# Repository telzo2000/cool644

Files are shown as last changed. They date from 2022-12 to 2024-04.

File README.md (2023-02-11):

# cool644
<br><br>

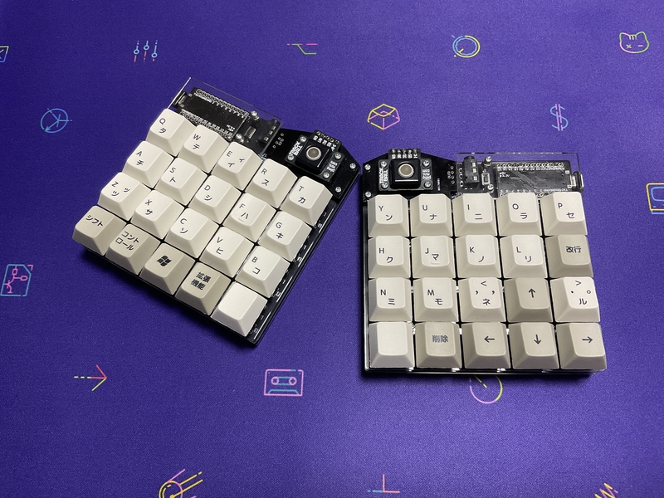
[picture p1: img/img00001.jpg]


# What is cool644?

<br>
cool644 is 40% keyboards.
<br>
cool644 is an evolution of cool640.
<br>
The cool644 can use rotary encoders and trackballs.
<br>
cool640 is written here.https://github.com/telzo2000/cool640

# History

ver.1.21 Compatible with AZ1UBALL
<br>
ver.1.1 First release
<br>
<br>
# Build guide 

https://github.com/telzo2000/cool644/blob/main/buildguide_for_cool644.md

<br>

# Sales site

https://booth.pm/ja/items/3729914

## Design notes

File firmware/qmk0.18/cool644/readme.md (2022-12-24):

# cool644

cool644

*A short description of the keyboard/project*

* Keyboard Maintainer: [m.ki](https://github.com/telzo2000)
* Hardware Supported: *The PCBs, controllers supported*
* Hardware Availability: *Links to where you can find this hardware*

Make example for this keyboard (after setting up your build environment):

    make cool644:default

Flashing example for this keyboard:

    make cool644:default:flash

See the [build environment setup](https://docs.qmk.fm/#/getting_started_build_tools) and the [make instructions](https://docs.qmk.fm/#/getting_started_make_guide) for more information. Brand new to QMK? Start with our [Complete Newbs Guide](https://docs.qmk.fm/#/newbs).

## Bootloader

Enter the bootloader in 3 ways:

* **Bootmagic reset**: Hold down the key at (0,0) in the matrix (usually the top left key or Escape) and plug in the keyboard
* **Physical reset button**: Briefly press the button on the back of the PCB - some may have pads you must short instead
* **Keycode in layout**: Press the key mapped to `QK_BOOT` if it is available

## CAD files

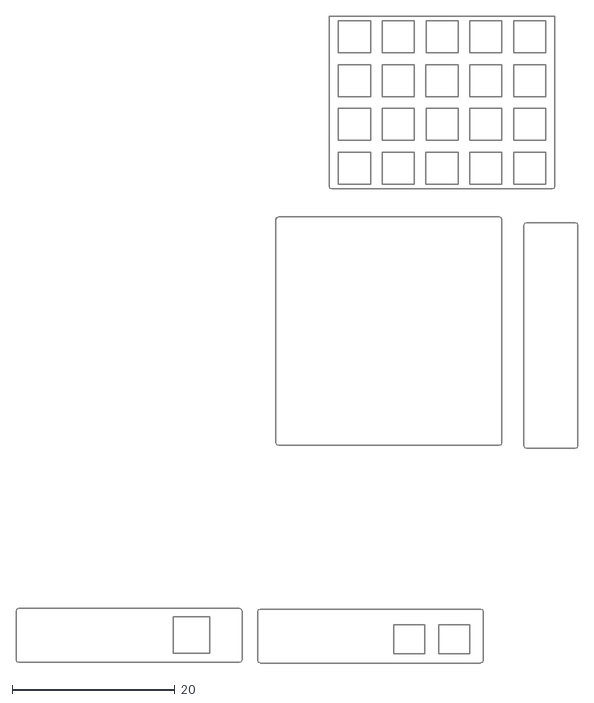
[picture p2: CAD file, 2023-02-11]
case_design/plate_elecrow200x250.dxf
69.0 x 79.4

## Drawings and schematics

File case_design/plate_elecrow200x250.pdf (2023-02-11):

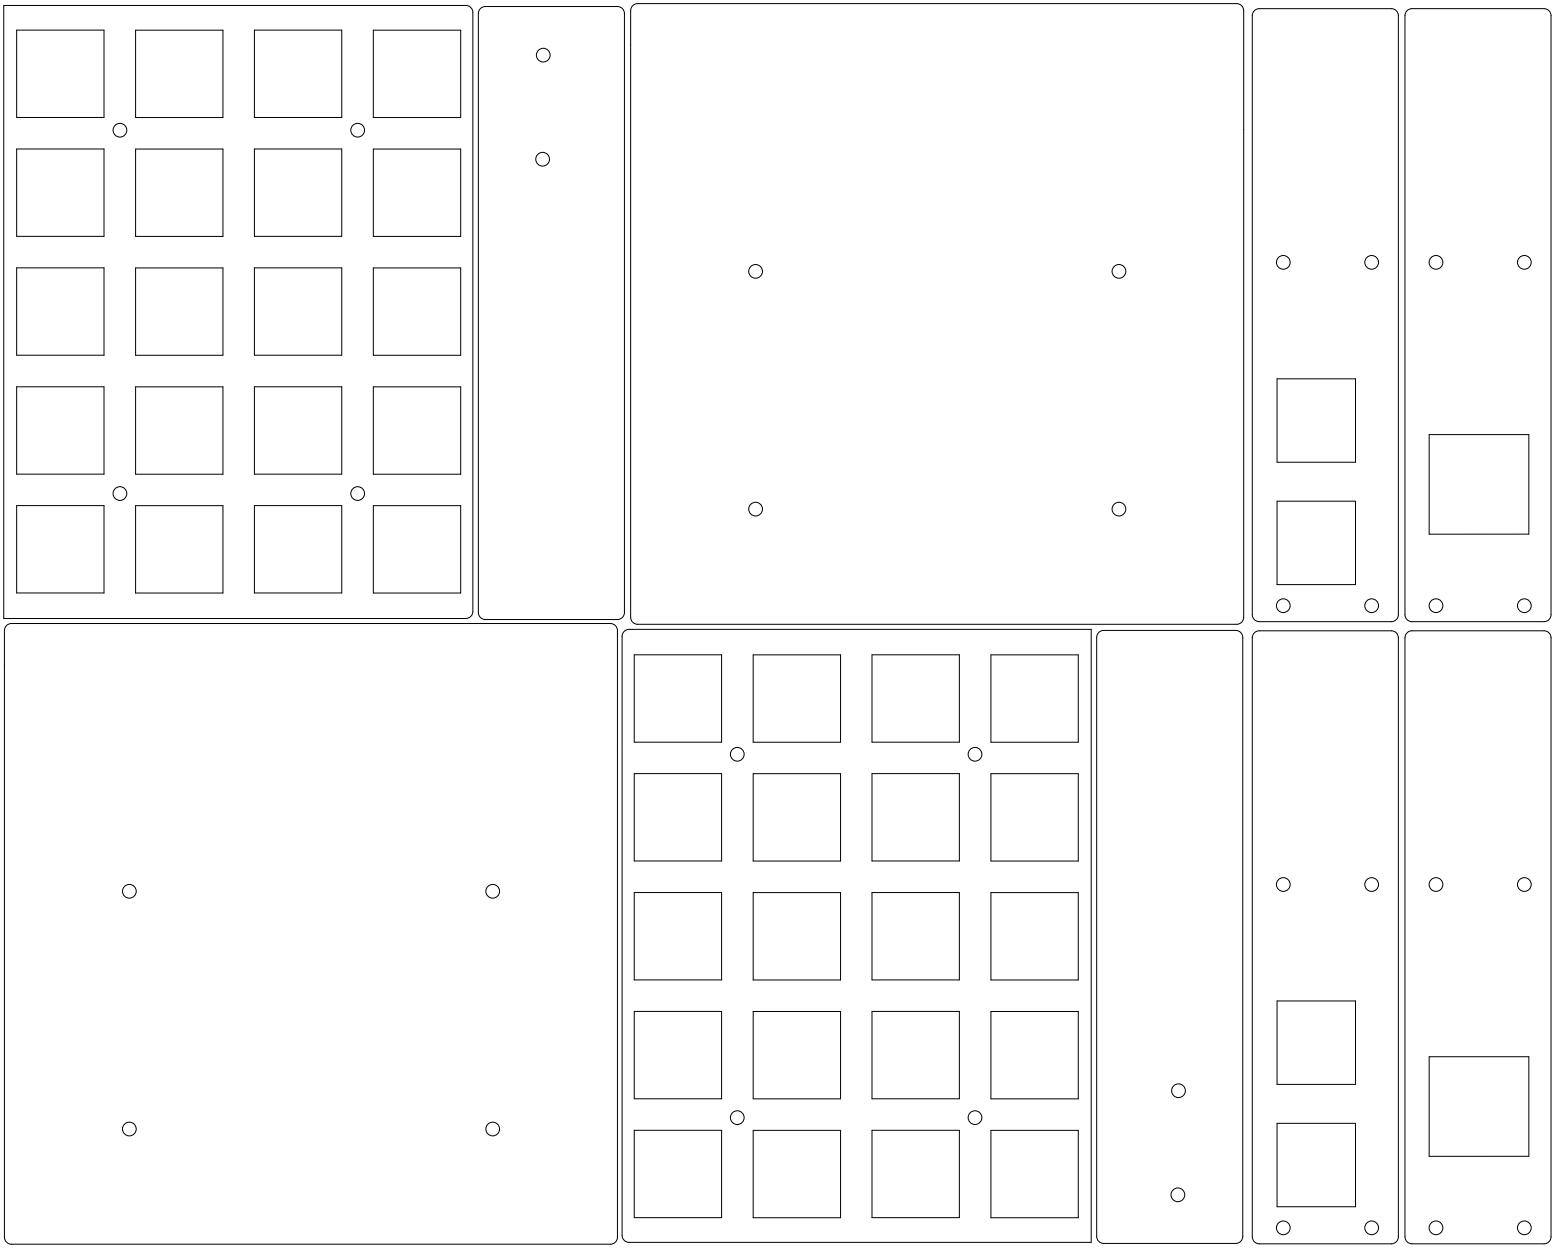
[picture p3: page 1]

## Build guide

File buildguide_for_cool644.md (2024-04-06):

# Build guide

## Parts list

| No. | Patrs | Quantity | remarks | Suppliers | Cost |
|--|--|--|--|--|--|
|番号|名前|数|備考|調達先|参考価格（送料込）|<br>
|1|PCB|2|40%splite keyboard|[elecrow](https://www.elecrow.com)<br>[JLCPCB](https://jlcpcb.com)<br>[ALLPCB](https://www.allpcb.com)|５枚で10〜20ドル|<br>
|2-1|Switch Plate<br>スイッチプレート|2|アクリル<br>[Plate data](https://github.com/telzo2000/cool536/tree/main/case_design)|[工房Emerge+](https://www.emergeplus.jp/laser-cutting-service/contact/)<br>[遊舎工房](https://yushakobo.jp)<br>[elecrow](https://www.elecrow.com)|種類による。|
|2-2|Cover Plate<br>カバープレート|2|↑|↑|↑|
|2-3|Bottom Plate<br>ボトムプレート|2|↑|↑|↑|
|3|M2screw<br>M2ネジ|8〜16|4mm<br>CoverPlateで使用<br>3mmでも代用可|DIYショップなど|10本で100円程度|
|4|M2screw<br>M2ネジ|8|3mm<br>BottomPlateで使用|↑|↑|
|5A|M2screw<br>M2ネジ|8|8mm<br>MXスイッチ使用時SwitchPlateで使用|↑|↑|
|5B|M2screw<br>M2ネジ|8|6mm<br>chocスッチ使用時SwitchPlateで使用|↑|↑|
|6A|M2spacer<br>M2スペーサー|16|3mmメス-メス<br>MXスイッチ使用時|[ヒロスギネット](https://www.hirosugi-net.co.jp/shop/c/c10/)<br>[遊舎工房](https://yushakobo.jp)|20本で800円程度|
|6B|M2spacer<br>M2スペーサー|8|3mmメス-メス<br>chocスイッチ使用時|[ヒロスギネット](https://www.hirosugi-net.co.jp/shop/c/c10/)<br>[遊舎工房](https://yushakobo.jp)|20本で800円程度|
|7|M2spacer<br>M2スペーサー|4〜8|6mmまたは8mmメス-メス<br>CoverPlateで使用|[ヒロスギネット](https://www.hirosugi-net.co.jp/shop/c/c10/)<br>[遊舎工房](https://yushakobo.jp)|20本で800円程度|
|8|pro micro|2|ピンヘッダも別途購入|[遊舎工房](https://yushakobo.jp)<br>[Talp Keyboard](https://talpkeyboard.net)<br>[Daily Craft Keyboard](https://shop.dailycraft.jp)等|価格変動中|
|9A|Swith socket<br>スイッチソケット|40|cherry MX互換|[遊舎工房](https://yushakobo.jp)<br>[Talp Keyboard](https://talpkeyboard.net)<br>[Daily Craft Keyboard](https://shop.dailycraft.jp)等|10個で165円程度|
|9B|Swith socket<br>スイッチソケット|40|choc互換|[遊舎工房](https://yushakobo.jp)<br>[Talp Keyboard](https://talpkeyboard.net)<br>[Daily Craft Keyboard](https://shop.dailycraft.jp)等|10個で165円程度|
|10|Diode<br>ダイオード|40〜44|リードタイプでもSMDでも可|[遊舎工房](https://yushakobo.jp)<br>[Talp Keyboard](https://talpkeyboard.net)<br>[Daily Craft Keyboard](https://shop.dailycraft.jp)等|100個で220円程度から|
|11|タクトスイッチ|2|２本足のもの|[遊舎工房](https://yushakobo.jp)<br>[Talp Keyboard](https://talpkeyboard.net)<br>[Daily Craft Keyboard](https://shop.dailycraft.jp)等|１個11円程度|
|12|TRRSジャック|2|MJ-4PP-9|[遊舎工房](https://yushakobo.jp)<br>[Talp Keyboard](https://talpkeyboard.net)<br>[Daily Craft Keyboard](https://shop.dailycraft.jp)等|１個55円|

In addition, you will need a TRRS cable, USB cable, keycaps, etc.
<br>
この他に、TRRSケーブル、USBケーブル、キーキャップ等が必要です。
<br>

## Firmware

###  QMK_FIRMWARE
[Here](https://github.com/telzo2000/cool644/tree/main/firmware)

<br>
[remap](https://remap-keys.app/)

<br>

## Build 1(PCB only)

### 1 Parts check

The cool644 is a PCB that uses both the front and back sides for left and right PCBs.
<br>
The part where the corner is cut diagonally will be the outside of the left and right.
<br>
<br>
cool644は左右のPCBに対して、表裏両面を使用するPCBです。
<br>
角が斜めにカットされている箇所が、左右の外側になります。
<br>

### 2 Diode soldering

Solder the diodes to the back of each of the left and right.
<br>
左右それぞれの裏面にダイオードのハンダ付けをします。
<br>

There are lead type and SMD diodes.
<br>
ダイオードはリードタイプか、SMDがあります。
<br>
Here, we will explain the lead type soldering.
<br>
ここでは、リードタイプのハンダ付けの説明をします。
<br>
However, those who adopt the choc switch should use SMD diodes.
<br>
ただし、chocスイッチを採用する人は、SMDのダイオードを使用してください。
<br>

Use a lead bender to bend the legs of the diode.
<br>
リードベンダーを使い、ダイオードの足を曲げます。
<br>

Insert the diode into the board.
<br>
ダイオードを基板に挿しこみます。
<br>

Please pay attention to the orientation of the diode.
<br>
ダイオードの向きに注意してください。
<br>

Secure the diode with masking tape, then face up.
<br>
マスキングテープでダイオードを固定してから、表面を上にします。
<br>
Solder the protruding legs.
<br>
はみ出ている足部分に、ハンダ付けをします。
<br>
After soldering, use nippers to cut off the protruding legs.
<br>
はんだ付けが終わったら、はみ出ている足をニッパーで切り取ってください。
<br>

[８倍速　Diodeハンダ付け動画](https://youtu.be/Yaodh2-XxV4)

<br>
<br>

### 3 Soldering switch sockets

Solder the switch sockets on the back side.
<br>
裏面にスイッチソケットのハンダ付けをします。
<br>
cool644 is compatible with both choc and cherry MX switches.
<br>
cool644はchocスイッチとcherryMXスイッチの両方に対応しています。
<br>
Both can be installed.
<br>
両方を取り付けることが可能です。
<br>
Here, solder the cherryMX switch.
<br>
ここでは、cherryMXスイッチのハンダ付けを行います。
<br>
Place the switch socket so that the letters MX are hidden.
<br>
MXという文字が隠れるように、スイッチソケットを乗せてください。
<br>
That is the correct switch socket orientation.
<br>
それが正しいスイッチソケットの向きになります。
<br>
When using a choc switch, place the switch socket so that the letters choc are hidden.
<br>
chocスイッチの時は、chocという文字が隠れるように、スイッチソケットを乗せてください。
<br>

Apply solder to both pads.
<br>
両方のパッドにハンダを盛ります。
<br>
Place the switch socket and fix it with a warm soldering iron while melting the solder.
<br>
スイッチソケットを乗せて、温めたハンダゴテで、ハンダを溶かしながら、固定します。
<br>
You can make it easier by working while holding it with tweezers.
<br>
ピンセットで押さえながら、作業をすると楽にできます。
<br>

[８倍速　Switch socketハンダ付け動画](https://youtu.be/E__mHvmIXQo)

<br><br>

### 4 Soldering reset switch & TRRS jack 

Insert the reset switch on the surface.
<br>
表面にリセットスイッチを挿しこみます。
<br>
Solder the legs of the reset switch from the back.
<br>
裏面からリセットスイッチの足をハンダ付けします。
<br>
Solder the TRRS jack in the same way near the reset switch.
<br>
TRRSジャックは、リセットスイッチの近くに同じようにハンダ付けします。
<br>
Insert the left and right TRRS jacks from the front side and solder from the back side.
<br>
TRRSジャックは左右１箇所ずつ、表面から差し込み、裏面からはんだ付けをしてください。
<br>

[８倍速　Reset switch,TRRS jackハンダ付け動画](https://youtu.be/3gEbExaOAv4)

<br><br>

### 5　Pro micro 

cool644 requires pro micro on each side.
<br>
cool644は左右それぞれにpro microが必要となります。
<br>

Use the conthrough to fix the pro micro with the side with the parts facing down.
<br>
pro microの部品のある面を下向きに、コンスルーを使い、固定してください。
<br>

Pay attention to the orientation of the conthrough.
<br>
コンスルーの向きに注意してください。
<br>

<br>

### 6　Test

Please write the firmware and check the operation.
<br>
ファームウェアを書き込んで、動作確認をしてください。
<br>

Install a switch or measure continuity with tweezers, etc.
<br>
スイッチを取り付けるか、ピンセット等で導通をはかるかを行います。
<br>

<br>

### QMK_FIRMWARE
[Here](https://github.com/telzo2000/cool644/tree/main/firmware)

参考<br>

https://github.com/telzo2000/Hello_keyboard/blob/main/readme_about_firmware.md

<br>
[remap](https://remap-keys.app/)

<br>

remapの画面
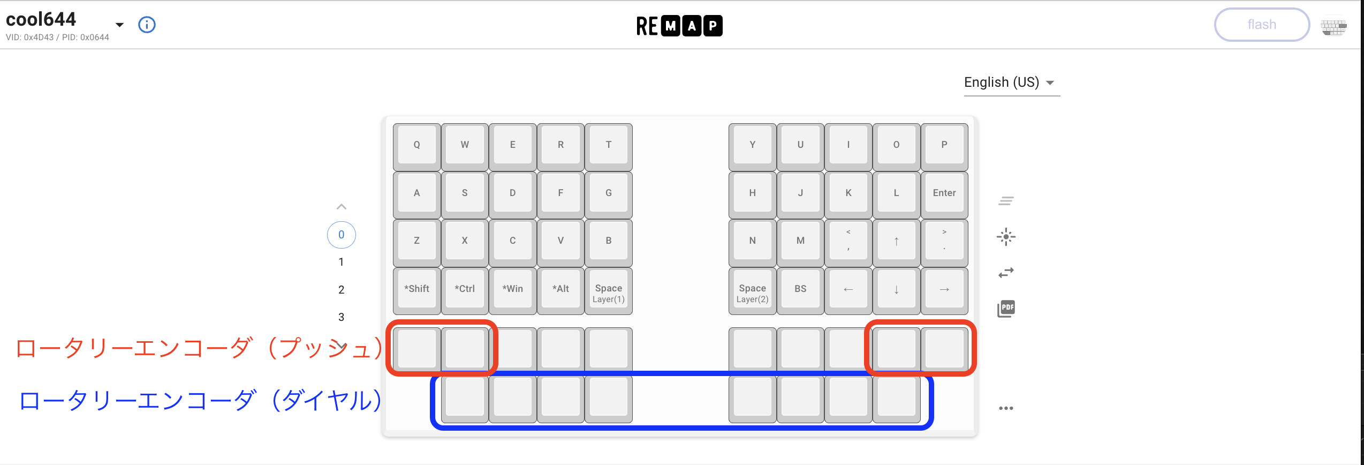
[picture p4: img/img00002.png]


<br>

### 7 Installation of key switch

Attach your favorite key switch.
<br>
好きなキースイッチを取り付けてください。
<br>

<br>
If you like, attach a rubber cushion to the back and you're done.
<br>
お好みで裏面にラバークッションを取り付けたら、完成です。
<br>
<br>
<br>

### Option 1 Installing a rotary encoder

cool644 can be equipped with 1 to 2 rotary encoders on the left and right, for a total of 4 rotary encoders.
<br>
cool644は、左右に１〜２個、合計４個のロータリーエンコーダーを取り付けることができます。
<br><br>

### Option 2 Mounting the OLED display

The left side of the cool644 can be fitted with an OLED display.
<br>
In that case, the rotary encoder cannot be attached to the left side of the cool644.
<br>
cool644の左側には、OLEDディスプレイを取り付けることができます。
<br>
その場合、cool644の左側には、ロータリーエンコーダーを取り付けることができません。
<br>
<br>

### OPtion 3 Installing PIM447 Trackball

You can install the PIM447 on either the left or right side.
<br>
In that case, you will need trackballpart.
<br><br>
左右どちらでも、PIM447を取り付けることができます。
<br>
その時は、trackballpartが必要となります。
<br>
<br>
In addition to PIM447 and trackballpart, you will need 10 M2 screws, 6 M2 spacers 3mm, and a pin header.
<br><br>
PIM447とtrackballpartの他に、M2ネジ10本、M2スペーサー3mm、ピンヘッダが必要となります。
<br><br>





<br><br><br>

## Build 2(Acrylic sandwich mount case)



After 1 ~ 6 of build1, please do the next step.
<br>
build1の1~6の後、次の工程をしてください。
<br>

### 1 Installation of cover plate

The same cover plate as cool640 can be used.
<br>
カバープレートはcool640と同じものが使えます。
<br>
And you can also use the cover plate dedicated to cool644.
<br>
そして、cool644専用のカバープレートも使えます。
<br><br>

Prepare a cover plate, M2 spacer 6or8mm（x４）, and M2 screw 4mm（x８）.
<br>
カバープレート、M2スペーサー6または8mm（４個）、M2ネジ3mm（８本）を用意します。
<br>
Screw the spacer to the cover plate in the same orientation.
<br>
カバープレートに同じ向きで、スペーサーをネジで固定します。
<br>
Then use the remaining screws to attach the cover plate to the PCB.
<br>
次に、残りのネジを使い、カバープレートをPCBに取り付けます。
<br>
There is an orientation of the cover plate, so it is good to check it once before starting work.
<br>
カバープレートの向きがあり、作業前に一度、重ねて確認すると良いです。
<br>
<br>
A special cover plate is required when installing a rotary encoder or an OLED display.
<br>
ロータリーエンコーダーまたはOLEDディスプレイを取り付けているとき、専用のカバープレートが必要となります。
<br><br>

### 2-1 Installation of switch plate（choc switch）

Prepare a switch plate, M2 spacer 3 mm（x４）, and M2 screw 6 mm（x４）.
<br>
スイッチプレート、M2スペーサー３mm（４本）、M2ネジ６mm（４本）を用意します。
<br>
Fix the screws in 4 places.
<br>
ネジを４箇所、固定します。
<br>
Insert the screws in the order of the switch plate and the PCB, and fix them with spacers on the back of the PCB.
<br>
ネジはスイッチプレート、PCBの順でさしこみ、PCBの裏面でスペーサーで固定します。
<br>

<br>

### 2-2 Installation of switch plate（cherry MX switch）

Prepare a switch plate, M2 spacer 3 mm（x８）, and M2 screw 8 mm（x４）.
<br>
スイッチプレート、M2スペーサー３mm（８本）、M2ネジ８mm（４本）を用意します。
<br>
Fix the screws in 4 places.
<br>
ネジを４箇所、固定します。
<br>
Insert the switch plate into the screw and fix it with a spacer.
<br>
ネジはスイッチプレートをさしこみ、スペーサーで固定します。
<br>
Next, insert the switch plate into the PCB and secure it with a spacer on the back of the PCB.
<br>
次に、スイッチプレートをPCBにさしこみ、PCBの裏面でスペーサーで固定します。
<br>

### 3 Installation of bottom plate 

Prepare the bottom plate and M2 ３mm screws（x４）.
<br>
ボトムプレート、M２ネジ３mm（４本）を用意します。
<br>
Place the bottom plate according to the spacer on the back of the PCB and fix it with screws.
<br>
PCB裏面にあるスペーサーに合わせて、ボトムプレートをのせて、ネジで固定します。
<br>
<br>
From here, proceed with step 7 of build1.
<br>
ここからは、build１の７の工程を進めてください。
<br>

Have a fun selfmade keyboard life!
<br>
楽しい自作キーボード生活を!



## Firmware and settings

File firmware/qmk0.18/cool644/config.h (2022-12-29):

// Copyright 2022 m.ki (@telzo2000)
// SPDX-License-Identifier: GPL-2.0-or-later

#pragma once

#include "config_common.h"

/* USB Device descriptor parameter */
#define VENDOR_ID    0x4D43
#define PRODUCT_ID   0x0644
#define DEVICE_VER   0x0001
#define MANUFACTURER telzo2000
#define PRODUCT      cool644

/* key matrix size */
#define MATRIX_ROWS 12
#define MATRIX_COLS 5

/*
 * Keyboard Matrix Assignments
 *
 * Change this to how you wired your keyboard
 * COLS: AVR pins used for columns, left to right
 * ROWS: AVR pins used for rows, top to bottom
 * DIODE_DIRECTION: COL2ROW = COL = Anode (+), ROW = Cathode (-, marked on diode)
 *                  ROW2COL = ROW = Anode (+), COL = Cathode (-, marked on diode)
 *
 */
#define MATRIX_ROW_PINS { B5, B4, B1, F7, F4, D0 }
#define MATRIX_COL_PINS { B2, B6, B3, F6, F5 }
#define MATRIX_ROW_PINS_RIGHT { B5, B4, B1, F7, F4, D0 }
#define MATRIX_COL_PINS_RIGHT { B2, B6, B3, F6, F5 }
#define UNUSED_PINS

/* COL2ROW, ROW2COL */
#define DIODE_DIRECTION ROW2COL
/*
 * Split Keyboard specific options, make sure you have 'SPLIT_KEYBOARD = yes' in your rules.mk, and define SOFT_SERIAL_PIN.
 */
#define SOFT_SERIAL_PIN D2  // or D1, D2, D3, E6

#define MASTER_LEFT
#define SOFT_SERIAL_PIN D2
//#define USE_I2C

#define ENCODERS_PAD_A {D4,D7 }
#define ENCODERS_PAD_B {C6,E6 }
#define ENCODERS_PAD_A_RIGHT {D7,D4 }
#define ENCODERS_PAD_B_RIGHT {E6,C6}


//#define LED_NUM_LOCK_PIN B0
//#define LED_CAPS_LOCK_PIN B1
//#define LED_SCROLL_LOCK_PIN B2
//#define LED_COMPOSE_PIN B3
//#define LED_KANA_PIN B4

//#define BACKLIGHT_PIN B7
//#define BACKLIGHT_LEVELS 3
//#define BACKLIGHT_BREATHING

#define RGB_DI_PIN D3
#ifdef RGB_DI_PIN
#    define RGBLED_NUM 16
#    define RGBLIGHT_HUE_STEP 8
#    define RGBLIGHT_SAT_STEP 8
#    define RGBLIGHT_VAL_STEP 8
#    define RGBLIGHT_LIMIT_VAL 255 /* The maximum brightness level */
#    define RGBLIGHT_SLEEP  /* If defined, the RGB lighting will be switched off when the host goes to sleep */
/*== all animations enable ==*/
#    define RGBLIGHT_ANIMATIONS
/*== or choose animations ==*/
#    define RGBLIGHT_EFFECT_BREATHING
#    define RGBLIGHT_EFFECT_RAINBOW_MOOD
#    define RGBLIGHT_EFFECT_RAINBOW_SWIRL
#    define RGBLIGHT_EFFECT_SNAKE
#    define RGBLIGHT_EFFECT_KNIGHT
#    define RGBLIGHT_EFFECT_CHRISTMAS
#    define RGBLIGHT_EFFECT_STATIC_GRADIENT
#    define RGBLIGHT_EFFECT_RGB_TEST
#    define RGBLIGHT_EFFECT_ALTERNATING
/*== customize breathing effect ==*/
/*==== (DEFAULT) use fixed table instead of exp() and sin() ====*/
#    define RGBLIGHT_BREATHE_TABLE_SIZE 256      // 256(default) or 128 or 64
/*==== use exp() and sin() ====*/
#    define RGBLIGHT_EFFECT_BREATHE_CENTER 1.85  // 1 to 2.7
#    define RGBLIGHT_EFFECT_BREATHE_MAX    255   // 0 to 255
#endif

/* Debounce reduces chatter (unintended double-presses) - set 0 if debouncing is not needed */
#define DEBOUNCE 5

/* define if matrix has ghost (lacks anti-ghosting diodes) */
//#define MATRIX_HAS_GHOST

/* Mechanical locking support. Use KC_LCAP, KC_LNUM or KC_LSCR instead in keymap */
#define LOCKING_SUPPORT_ENABLE
/* Locking resynchronize hack */
#define LOCKING_RESYNC_ENABLE

/* If defined, GRAVE_ESC will always act as ESC when CTRL is held.
 * This is useful for the Windows task manager shortcut (ctrl+shift+esc).
 */
//#define GRAVE_ESC_CTRL_OVERRIDE

/*
 * Force NKRO
 *
 * Force NKRO (nKey Rollover) to be enabled by default, regardless of the saved
 * state in the bootmagic EEPROM settings. (Note that NKRO must be enabled in the
 * makefile for this to work.)
 *
 * If forced on, NKRO can be disabled via magic key (default = LShift+RShift+N)
 * until the next keyboard reset.
 *
 * NKRO may prevent your keystrokes from being detected in the BIOS, but it is
 * fully operational during normal computer usage.
 *
 * For a less heavy-handed approach, enable NKRO via magic key (LShift+RShift+N)
 * or via bootmagic (hold SPACE+N while plugging in the keyboard). Once set by
 * bootmagic, NKRO mode will always be enabled until it is toggled again during a
 * power-up.
 *
 */
//#define FORCE_NKRO

/*
 * Feature disable options
 *  These options are also useful to firmware size reduction.
 */

/* disable debug print */
//#define NO_DEBUG

/* disable print */
//#define NO_PRINT

/* disable action features */
//#define NO_ACTION_LAYER
//#define NO_ACTION_TAPPING
//#define NO_ACTION_ONESHOT

/* disable these deprecated features by default */
#define NO_ACTION_MACRO
#define NO_ACTION_FUNCTION

/* Bootmagic Lite key configuration */
//#define BOOTMAGIC_LITE_ROW 0
//#define BOOTMAGIC_LITE_COLUMN 0

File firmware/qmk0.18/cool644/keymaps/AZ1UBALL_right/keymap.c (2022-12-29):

// Copyright 2022 m.ki (@telzo2000)
// SPDX-License-Identifier: GPL-2.0-or-later

#include QMK_KEYBOARD_H

// Defines names for use in layer keycodes and the keymap
enum layer_names {
  _QWERTY,
    _LOWER,
    _RAISE,
    _ADJUST,
};

// Defines the keycodes used by our macros in process_record_user
enum custom_keycodes {
    QWERTY = SAFE_RANGE,
    LOWER,
    RAISE,
    ADJUST,
};

const uint16_t PROGMEM keymaps[][MATRIX_ROWS][MATRIX_COLS] = {
    
    [_QWERTY] = LAYOUT(
    KC_Q,    KC_W,    KC_E,    KC_R,    KC_T,               KC_Y,               KC_U,     KC_I,     KC_O,    KC_P,    
    KC_A,    KC_S,    KC_D,    KC_F,    KC_G,               KC_H,               KC_J,     KC_K,     KC_L,    KC_ENT,    
    KC_Z,    KC_X,    KC_C,    KC_V,    KC_B,               KC_N,               KC_M,     KC_COMM,  KC_UP,  KC_DOT, 
    KC_LSFT, KC_LCTL, KC_LGUI, KC_LALT, LT(_LOWER,KC_SPACE),LT(_RAISE,KC_SPACE),KC_BSPC,  KC_LEFT,  KC_DOWN, KC_RIGHT,
    KC_NO,KC_NO,KC_NO,KC_NO,KC_NO,KC_NO,KC_NO,KC_NO,KC_NO,KC_NO,
    KC_NO,KC_NO,KC_NO,KC_NO,KC_NO,KC_NO,KC_NO,KC_NO
  ),
  
  [_LOWER] = LAYOUT(
    KC_1,     KC_2,      KC_3,      KC_4,      KC_5,                KC_6,                KC_7,     KC_8,          KC_9,           KC_0,    
    KC_EXLM,  KC_AT,     KC_HASH,   KC_DLR,    KC_PERC,             KC_CIRC,             KC_AMPR,  KC_ASTR,       KC_LPRN,        KC_RPRN, 
    KC_PPLS,  KC_PMNS,   KC_PAST,   KC_PSLS,   KC_PEQL,             KC_GRV,              KC_JYEN,  RSFT(KC_LBRC), RSFT(KC_RBRC),  RSFT(KC_MINS),
    KC_TAB,   KC_INSERT, KC_SPACE,  KC_SPACE,  LT(_LOWER,KC_SPACE), LT(_RAISE,KC_SPACE), KC_LCTL,  KC_LGUI,       KC_LALT,        KC_BSPC,
    KC_NO,KC_NO,KC_NO,KC_NO,KC_NO,KC_NO,KC_NO,KC_NO,KC_NO,KC_NO,
     KC_NO,KC_NO,KC_NO,KC_NO,KC_NO,KC_NO,KC_NO,KC_NO
  ) ,
 
  
  [_RAISE] = LAYOUT(
    KC_F1,    KC_F2,      KC_F3,      KC_F4,          KC_F5,               KC_F6,               KC_F7,    KC_F8,     KC_F9,     KC_F10,    
    KC_AT,    KC_BSLS,    KC_SCLN,    RSFT(KC_SCLN),  KC_QUOT,             KC_LEFT,             KC_DOWN,  KC_UP,     KC_RIGHT,  KC_EQL,
    RGB_TOG,  RGB_MOD,    RGB_HUI,    RGB_HUD,        RGB_SAI,             RGB_SAD,             RGB_VAI,  KC_LBRC,   KC_RBRC,   KC_BSLASH,
    KC_TAB,   KC_INSERT,  KC_SPACE,   KC_SPACE,       LT(_LOWER,KC_SPACE), LT(_RAISE,KC_SPACE), KC_LCTL,  KC_LGUI,   KC_LALT,   KC_BSPC,
    KC_NO,KC_NO,KC_NO,KC_NO,KC_NO,KC_NO,KC_NO,KC_NO,KC_NO,KC_NO,
     KC_NO,KC_NO,KC_NO,KC_NO,KC_NO,KC_NO,KC_NO,KC_NO
  ) 
};

keyevent_t encoder1_ccw = {
    .key = (keypos_t){.row = 5, .col = 0},
    .pressed = false
};

keyevent_t encoder1_cw = {
    .key = (keypos_t){.row = 5, .col = 1},
    .pressed = false
};

keyevent_t encoder2_ccw = {
    .key = (keypos_t){.row = 5, .col = 2},
    .pressed = false
};

keyevent_t encoder2_cw = {
    .key = (keypos_t){.row = 5, .col = 3},
    .pressed = false
};

keyevent_t encoder3_ccw = {
    .key = (keypos_t){.row = 11, .col = 1},
    .pressed = false
};

keyevent_t encoder3_cw = {
    .key = (keypos_t){.row = 11, .col = 0},
    .pressed = false
};

keyevent_t encoder4_ccw = {
    .key = (keypos_t){.row = 11, .col = 3},
    .pressed = false
};

keyevent_t encoder4_cw = {
    .key = (keypos_t){.row = 11, .col = 2},
    .pressed = false
};


void matrix_scan_user(void) {
    if (IS_PRESSED(encoder1_ccw)) {
        encoder1_ccw.pressed = false;
        encoder1_ccw.time = (timer_read() | 1);
        action_exec(encoder1_ccw);
    }

    if (IS_PRESSED(encoder1_cw)) {
        encoder1_cw.pressed = false;
        encoder1_cw.time = (timer_read() | 1);
        action_exec(encoder1_cw);
    }

    if (IS_PRESSED(encoder2_ccw)) {
        encoder2_ccw.pressed = false;
        encoder2_ccw.time = (timer_read() | 1);
        action_exec(encoder2_ccw);
    }

    if (IS_PRESSED(encoder2_cw)) {
        encoder2_cw.pressed = false;
        encoder2_cw.time = (timer_read() | 1);
        action_exec(encoder2_cw);
    }

    if (IS_PRESSED(encoder3_ccw)) {
        encoder3_ccw.pressed = false;
        encoder3_ccw.time = (timer_read() | 1);
        action_exec(encoder3_ccw);
    }

    if (IS_PRESSED(encoder3_cw)) {
        encoder3_cw.pressed = false;
        encoder3_cw.time = (timer_read() | 1);
        action_exec(encoder3_cw);
    }

    if (IS_PRESSED(encoder4_ccw)) {
        encoder4_ccw.pressed = false;
        encoder4_ccw.time = (timer_read() | 1);
        action_exec(encoder4_ccw);
    }

    if (IS_PRESSED(encoder4_cw)) {
        encoder4_cw.pressed = false;
        encoder4_cw.time = (timer_read() | 1);
        action_exec(encoder4_cw);
    }
}

bool encoder_update_user(uint8_t index, bool clockwise) {
    if (index == 0) {
        if (clockwise) {
            encoder1_cw.pressed = true;
            encoder1_cw.time = (timer_read() | 1);
            action_exec(encoder1_cw);
        } else {
            encoder1_ccw.pressed = true;
            encoder1_ccw.time = (timer_read() | 1);
            action_exec(encoder1_ccw);
        }
    } else if (index == 1) {
        if (clockwise) {
            encoder2_cw.pressed = true;
            encoder2_cw.time = (timer_read() | 1);
            action_exec(encoder2_cw);
        } else {
            encoder2_ccw.pressed = true;
            encoder2_ccw.time = (timer_read() | 1);
            action_exec(encoder2_ccw);
        }
    } else if (index == 2) {
        if (clockwise) {
            encoder3_cw.pressed = true;
            encoder3_cw.time = (timer_read() | 1);
            action_exec(encoder3_cw);
        } else {
            encoder3_ccw.pressed = true;
            encoder3_ccw.time = (timer_read() | 1);
            action_exec(encoder3_ccw);
        }
    } else if (index == 3) {
        if (clockwise) {
            encoder4_cw.pressed = true;
            encoder4_cw.time = (timer_read() | 1);
            action_exec(encoder4_cw);
        } else {
            encoder4_ccw.pressed = true;
            encoder4_ccw.time = (timer_read() | 1);
            action_exec(encoder4_ccw);
        }
    }

    return true;
}
